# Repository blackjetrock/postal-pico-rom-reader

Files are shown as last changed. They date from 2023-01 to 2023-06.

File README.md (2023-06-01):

# Postal Pico ROM Reader

This is a ROM reader that is designed to be an easy to use, simple ROM dumping tool.
It should be possible to send the dumper to someone in the post, have them plug a ROM in and get
a dump of that ROM stored in the device flash. The device can then optionally dump
more ROMs and then be sent back to the person who wants the dumps. The dumps are then extracted from the 
device flash.

 <b>*** NOTE: Make sure pin 1 of the ROM is correctly aligned with pin 1 on the socket when inserting it ***</b>

The dumper can also dump ROM contents to the USB port it is powered by.



Hardware
========

The dumper is basically just a Pico attached to a ROM socket with serial resistors. It is making use of the 
possible/probably 5V tolerance of its GPIO lines-*-. The control signals are attached through low value 
resistors as they drive the ROM and aren't subject to 5V. The data lines are 5V and come into the Pico
though cowardly 28K resistors. 

Firmware
========

The firmware uses the USB serial port for interactions with the user. It uses the flash of the Pico for firmware 
and also has configuration data stored in part of the flash. ROM dumps stored in several 'slots' of 16K each so
an external non-volatile device isn't needed.
the USB serial has a menu system that can be entered at boot-up and used to set the non-volatile
configuration data that determines how the dumper will work. Slots can be cleared etc and data dumped from the menu
system.

The dumper can be set up to dump to USB or dump data to a flash slot using the configuration menu. When dumping to a 
slot the data is also dumped to USB. Once all slots are full the dumper will not over-write any slots with new dumps,
but the device can still be used as a dumper with a USB data dump.

To delete the slots a menu option is used, and several hoops have to be jumped through.

There are a couple of counters that count the number of USB dumps that the dumper has taken and the number of slot dumps it has performed.

-*-I saw a post on the internet, which if it really is by Eben Upton, says that the Pico GPIOs are
5V tolerant, but not 5V5 tolerant as inputs.

See here:

https://hackaday.com/2022/09/25/pi-pico-w-does-pcmcia-gets-this-ibm-pc110-online/#comment-6516402

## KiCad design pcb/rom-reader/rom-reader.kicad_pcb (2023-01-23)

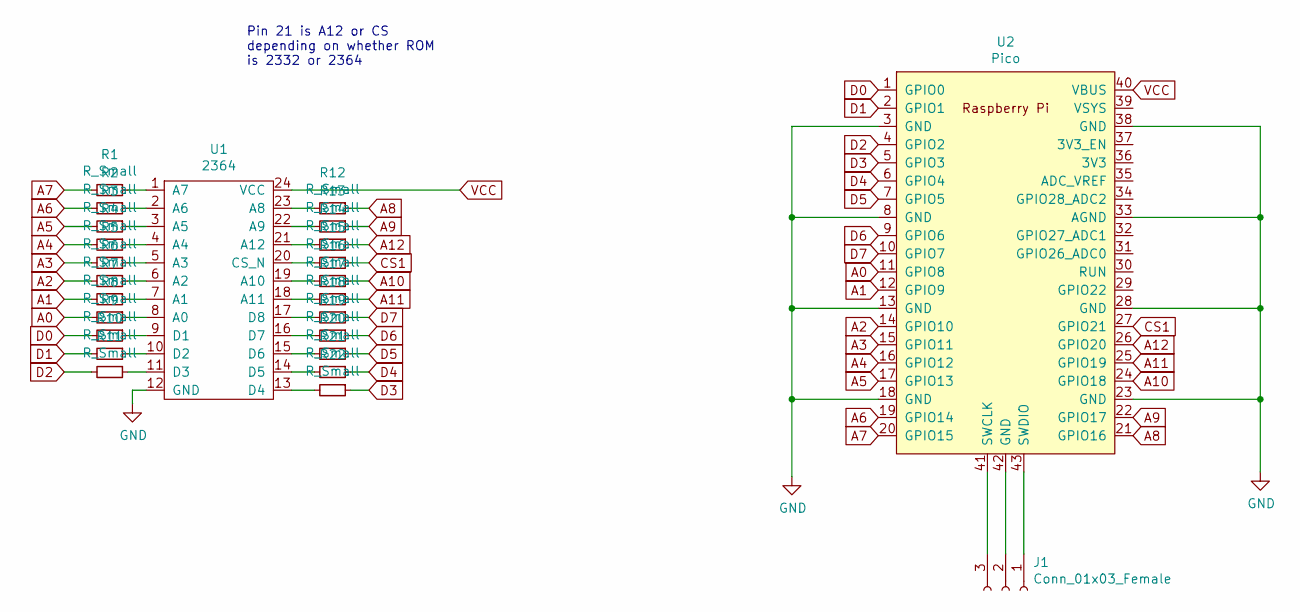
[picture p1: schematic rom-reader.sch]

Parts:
J1: Conn_01x03_Female; PinHeader_1x03_P2.54mm_Vertical
R1, R2, R3, R4, R5, R6, R7, R8, R9, R10, R11, R12, R13, R14, R15, R16, R17, R18, R19, R20, R21, R22: R_Small; R_0805_2012Metric_Pad1.20x1.40mm_HandSolder
U1: 2364; DIP-24_W15.24mm
U2: Pico; RPi_Pico_SMD_TH

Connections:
A0: R8.2, U2.11 (GPIO8)
A1: R7.2, U2.12 (GPIO9)
A2: R6.2, U2.14 (GPIO10)
A3: R5.2, U2.15 (GPIO11)
A4: R4.2, U2.16 (GPIO12)
A5: R3.2, U2.17 (GPIO13)
A6: R2.2, U2.19 (GPIO14)
A7: R1.2, U2.20 (GPIO15)
A8: R12.1, U2.21 (GPIO16)
A9: R13.1, U2.22 (GPIO17)
A10: R16.1, U2.24 (GPIO18)
A11: R17.1, U2.25 (GPIO19)
A12: R14.1, U2.26 (GPIO20)
CS1: R15.1, U2.27 (GPIO21)
D0: R9.2, U2.1 (GPIO0)
D1: R10.2, U2.2 (GPIO1)
D2: R11.2, U2.4 (GPIO2)
D3: R22.1, U2.5 (GPIO3)
D4: R21.1, U2.6 (GPIO4)
D5: R20.1, U2.7 (GPIO5)
D6: R19.1, U2.9 (GPIO6)
D7: R18.1, U2.10 (GPIO7)
GND: U1.12 (GND), U2.3 (GND), U2.8 (GND), U2.13 (GND), U2.18 (GND), U2.23 (GND), U2.28 (GND), U2.33 (AGND), U2.38 (GND)
unnamed: J1.1, U2.43 (SWDIO)
unnamed: J1.2, U2.42 (GND)
unnamed: J1.3, U2.41 (SWCLK)
unnamed: R1.1, U1.1 (A7)
unnamed: R2.1, U1.2 (A6)
unnamed: R3.1, U1.3 (A5)
unnamed: R4.1, U1.4 (A4)
unnamed: R5.1, U1.5 (A3)
unnamed: R6.1, U1.6 (A2)
unnamed: R7.1, U1.7 (A1)
unnamed: R8.1, U1.8 (A0)
unnamed: R9.1, U1.9 (D1)
unnamed: R10.1, U1.10 (D2)
unnamed: R11.1, U1.11 (D3)
unnamed: R12.2, U1.23 (A8)
unnamed: R13.2, U1.22 (A9)
unnamed: R14.2, U1.21 (A12)
unnamed: R15.2, U1.20 (CS_N)
unnamed: R16.2, U1.19 (A10)
unnamed: R17.2, U1.18 (A11)
unnamed: R18.2, U1.17 (D8)
unnamed: R19.2, U1.16 (D7)
unnamed: R20.2, U1.15 (D6)
unnamed: R21.2, U1.14 (D5)
unnamed: R22.2, U1.13 (D4)
VCC: U1.24 (VCC), U2.40 (VBUS)

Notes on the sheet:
Pin 21 is A12 or CS depending on whether ROM is 2332 or 2364

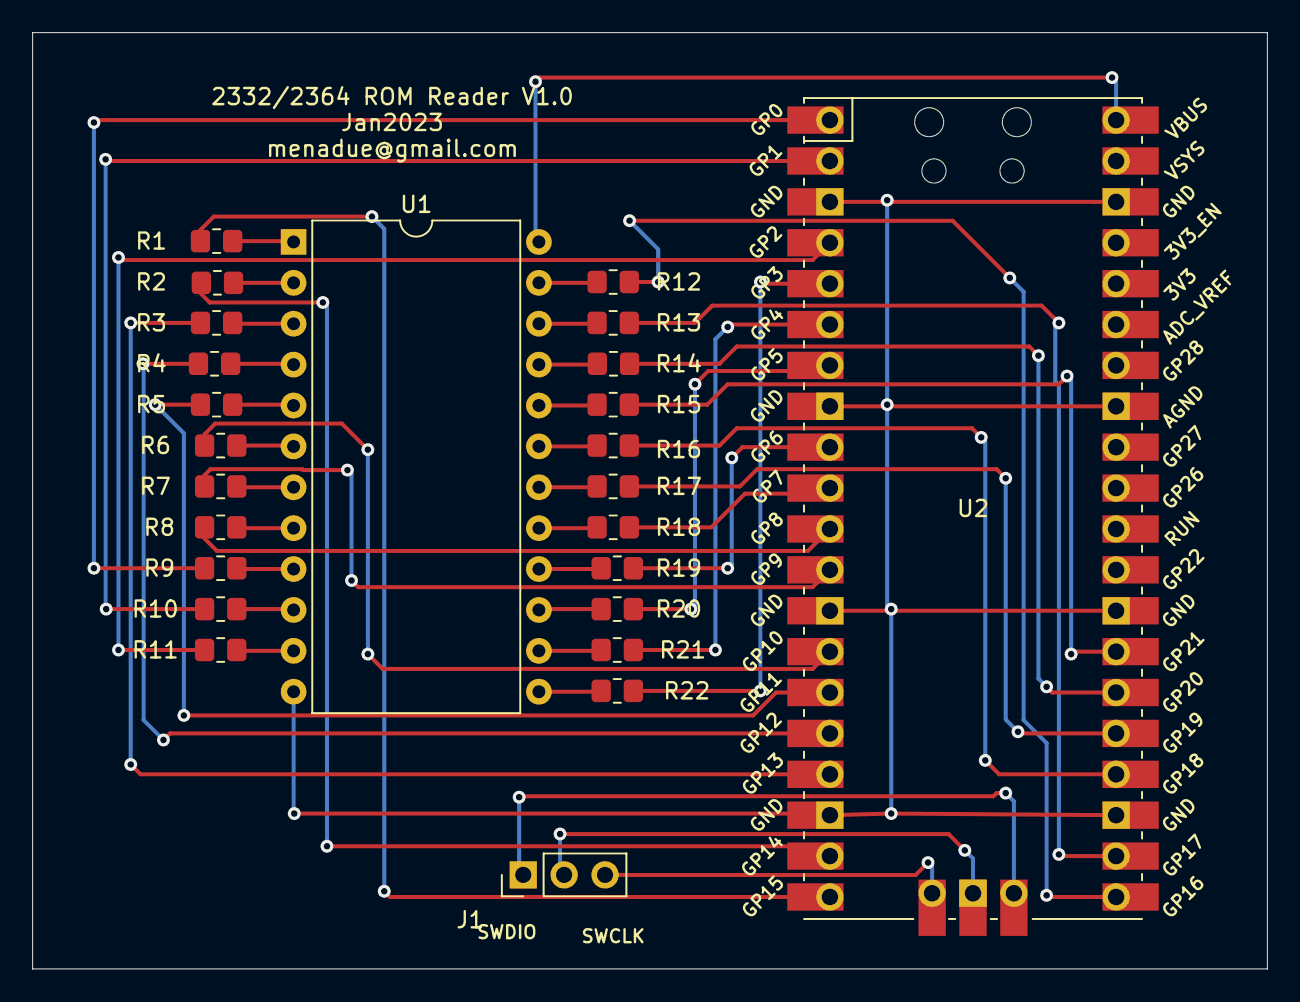
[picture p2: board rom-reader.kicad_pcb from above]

Board: 2 copper layers, 76.7 x 58.2 mm, 25 parts (0 on the bottom side), 49 nets.

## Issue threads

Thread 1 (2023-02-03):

Add license information

vazhnov, 2023-02-03:
Hello!

I found this project from https://hackaday.com/2023/02/02/a-disposable-dumper-for-rom-chips-with-a-pi-pico/

Could you please add information about the license of this repository — is it allowed to copy, change and use the code and design files in any purpose?
It would be great to see any popular open source license.

vazhnov, 2023-02-03:
Sounds like MIT for a code and CC0 / CC-BY for PCB files :)

vazhnov, 2023-02-03:
GPL is good for a code (if you know why some developers don't like GPL) but probably it is not clear for PCB files. I'm not **so** good in licensing.

Anyway it is much better than no license at all (100% proprietary).

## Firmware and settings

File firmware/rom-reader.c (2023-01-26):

////////////////////////////////////////////////////////////////////////////////
//
// Pico ROM Reader
//
// Reads data out of a 24 pin EPROM
// Data is dumped onto the USB serial
//
// A startup option allows configuration data to be set up.
// At the top of flash memory we have two areas. One holds config
// data and one holds slots for ROM dumps. The tool only works with up to
// 16K ROMs so we have 16K slots. Slots are only ever filled by the dump code
// once full the slot have to be deleted with a flash sector erase.
//
////////////////////////////////////////////////////////////////////////////////

#include <ctype.h>
#include <stdio.h>
#include <string.h>
#include <stdlib.h>
#include <time.h>
#include "pico/stdlib.h"
//##include "hardware/pio.h"
//##include "hardware/clocks.h"
#include "hardware/flash.h"

// Use this if breakpoints don't work
#define DEBUG_STOP {volatile int x = 1; while(x) {} }

////////////////////////////////////////////////////////////////////////////////
//
//

// Only scan once, if multiple dumps needed then use a loop around the entire tool
// This makes the post processing easier.

#define NUM_SCANS    1
#define SLOT_SIZE    (16*1024)

// How many slots there are. We could have very many slots, why not?
#define NUM_SLOTS    50

//-----------------------------------------------------------------------------

// Config sector
#define FLASH_CONFIG_OFFSET (1024 * 1024)
uint8_t *flash_config_contents = (uint8_t *) (XIP_BASE + FLASH_CONFIG_OFFSET);

// ROM image slots
#define FLASH_SLOT_OFFSET (1028 * 1024)
uint8_t *flash_slot_contents   = (uint8_t *) (XIP_BASE + FLASH_SLOT_OFFSET);


//--------------------------------------------------------------------------------

typedef enum
  {
   USB_DUMP = 0,
   SLOT_DUMP,
   NUM_SETUP_MODES,
  } SETUP_MODE;

char *setup_mode_name[NUM_SETUP_MODES] =
  {
   "USB DUMP",
   "SLOT_DUMP",
  };

typedef struct {
  int valid_a;     // magic number and an 
  int valid_b;     // inverterted magic number
  int mode;        // Mode we are in
  int usb_dump_count;   // Incremented after every dump
  int slot_dump_count;  // Incremented after every slot dump
} CONFIG_RECORD;

CONFIG_RECORD *config_record = (CONFIG_RECORD *) (XIP_BASE + FLASH_CONFIG_OFFSET);
CONFIG_RECORD copy_config_record;

#define CONFIG_MAGIC_A 0xCFAA0134
#define CONFIG_MAGIC_B 0xCFBB5623

// RAM slot which we copy to flash once filled
uint8_t slot_data[SLOT_SIZE];

//--------------------------------------------------------------------------------

void dump_slot(int slotnum);
void display_slot_map(void);
void clear_slot_data(void);

//------------------------------------------------------------------------------

const int LED_PIN = 25;

const int D0_PIN = 0;
const int D1_PIN = 1;
const int D2_PIN = 2;
const int D3_PIN = 3;
const int D4_PIN = 4;
const int D5_PIN = 5;
const int D6_PIN = 6;
const int D7_PIN = 7;

//
// The address lines (always inputs)
//
const int  A0_PIN  =  8;
const int  A1_PIN  =  9;
const int  A2_PIN  = 10;
const int  A3_PIN  = 11;
const int  A4_PIN  = 12;
const int  A5_PIN  = 13;
const int  A6_PIN  = 14;
const int  A7_PIN  = 15;
const int  A8_PIN  = 16;
const int  A9_PIN  = 17;
const int  A10_PIN = 18;
const int  A11_PIN = 19;
const int  A12_PIN = 20;
const int  A13_PIN = 21;  // Actually CS pin sometimes but can scan as if it was an address line

// Arrays for setting GPIOs up
#define NUM_ADDR 14
#define NUM_DATA 8

const int address_pins[NUM_ADDR] =
  {
   A0_PIN,
   A1_PIN,
   A2_PIN,
   A3_PIN,
   A4_PIN,
   A5_PIN,
   A6_PIN,
   A7_PIN,
   A8_PIN,
   A9_PIN,
   A10_PIN,
   A11_PIN,
   A12_PIN,
   A13_PIN,   // Could be CS pin
  };

const int data_pins[NUM_DATA] =
  {
   D0_PIN,
   D1_PIN,
   D2_PIN,
   D3_PIN,
   D4_PIN,
   D5_PIN,
   D6_PIN,
   D7_PIN,
  };

////////////////////////////////////////////////////////////////////////////////
//
// Set the address lines to a value
//
////////////////////////////////////////////////////////////////////////////////

void set_address(int addr)
{
  for(int i=0; i<NUM_ADDR; i++)
    {
      if( addr & (1<<i) )
	{
	  gpio_put(address_pins[i], 1);
	}
      else
	{
	  gpio_put(address_pins[i], 0);
	}
    }
}


int read_data(void)
{
  int result = 0;
  
  for(int i=0; i<NUM_DATA; i++)
    {
      if( gpio_get(data_pins[i]) )
	{
	  result |= (1 << i);
	}
    }
  return(result);
}

////////////////////////////////////////////////////////////////////////////////


void print_hex(uint8_t *buf, int len)
{
  for (size_t i = 0; i < len; ++i)
    {
      if((i % 16) == 0)
	{
	  printf("\n");
	}
      
      printf("%02x ", buf[i]);
    }
}

////////////////////////////////////////////////////////////////////////////////

void prompt(void)
{
  printf("\n>");
}

void setup_menu(void)
{
  printf("\nSetup");
  printf("\n=====");
  printf("\n");
  printf("\n?: Display menu");
  printf("\nq: Quit");
  printf("\nc: Clear config settings");
  printf("\nC: Clear slot data");
  printf("\nd: Display config settings");
  printf("\np: Print information");
  printf("\nP: Dump config sector");
  printf("\nU: Set USB dump mode");
  printf("\nS: Set slot dump mode");
  printf("\nM: Display slot map");
  printf("\nr: Display slot");
  printf("\nz: Zero USB dump count");
  printf("\nZ: Zero Slot dump count");
}

void erase_config_sector(void)
{
  flash_range_erase(FLASH_CONFIG_OFFSET, FLASH_SECTOR_SIZE);
}

void erase_slot_data(void)
{
  flash_range_erase(FLASH_SLOT_OFFSET, SLOT_SIZE*NUM_SLOTS);
}

void program_config_record(CONFIG_RECORD *data)
{
  flash_range_program(FLASH_CONFIG_OFFSET,(uint8_t *) data, sizeof(CONFIG_RECORD));
}

void write_config_record(CONFIG_RECORD *cfg_rec)
{
  // Make record valid
  cfg_rec->valid_a = CONFIG_MAGIC_A;
  cfg_rec->valid_b = CONFIG_MAGIC_B;
  
  erase_config_sector();
  program_config_record(cfg_rec);
}

void zero_usb_dump_count(void)
{
  copy_config_record = *config_record;
  copy_config_record.usb_dump_count = 0;
  write_config_record(&copy_config_record);
}

void zero_slot_dump_count(void)
{
  copy_config_record = *config_record;
  copy_config_record.slot_dump_count = 0;
  write_config_record(&copy_config_record);
}

void increment_usb_dump_count(void)
{
  copy_config_record = *config_record;
  (copy_config_record.usb_dump_count)++;
  write_config_record(&copy_config_record);
}

void increment_slot_dump_count(void)
{
  copy_config_record = *config_record;
  (copy_config_record.slot_dump_count)++;
  write_config_record(&copy_config_record);
}

//--------------------------------------------------------------------------------

void write_data_to_slot(uint8_t *data, int slotnum)
{
  printf("\nWriting data to slot %d", slotnum);

  flash_range_program(FLASH_SLOT_OFFSET + (SLOT_SIZE * slotnum), (uint8_t *) data, SLOT_SIZE);

  printf("\nData written");
  
}

//--------------------------------------------------------------------------------
//

int slot_is_blank(int slotnum)
{
  int blank = 0;
  
  // See if all bytes in this slot are 0xff
  // Assume blank

  blank = 1;

  for(int j=0; j<SLOT_SIZE;j++)
    {
      if( *(flash_slot_contents+slotnum*SLOT_SIZE+j) !=0xFF )
	{
	  // Not blank
	  blank = 0;
	  break;
	}
    }
  
  if( blank )
    {
      // We found a slot, return its index
      return(1);
    }

  return(0);
}

//--------------------------------------------------------------------------------
//
// Find a slot that has no data in it, i.e. is full of 0xFF
// returns either the slot number or -1 if none are blank

int find_blank_slot(void)
{
  int slotnum = -1;
  
  for(slotnum=0; slotnum<NUM_SLOTS; slotnum++)
    {
      if( slot_is_blank(slotnum) )
	{
	  return(slotnum);
	}
    }

  return(-1);
}

char *get_mode_name(int mode)
{
  switch(mode)
    {
    case USB_DUMP:
    case SLOT_DUMP:
      return(setup_mode_name[mode]);      
      break;

    default:
      return("Unknown");
      break;
    }
}

////////////////////////////////////////////////////////////////////////////////
//
// Check for entry into the setup code
//
////////////////////////////////////////////////////////////////////////////////

void check_config_entry(void)
{
  int c;
  int key_pressed = 0;

  printf("\nPress any key to enter setup...\n");
  
  // Wait for a while and see if a keypress occurred
  for(int i=0; i<5; i++)
    {
      printf("  %d...", i);
      
      sleep_ms(1000);

      if( (c = getchar_timeout_us(1000)) != PICO_ERROR_TIMEOUT )
	{
	  if( (c != 0) && (c != 255) )
	    {
	      key_pressed = 1;
	      break;
	    }
	}
    }

  if( key_pressed )
    {
      printf("\nkey %d pressed", c);

      // Key was pressed, enter setup loop

      int done = 0;

      setup_menu();
      prompt();
      
      while(!done)
	{
	  if( (c = getchar_timeout_us(1000)) != PICO_ERROR_TIMEOUT )
	    {
	      // handle command
	      switch(c)
		{
		case '?':
		  setup_menu();
		  break;
		  
		case 'q':
		  done = 1;
		  break;

		case 'd':
		  printf("\nConfiguration data:");
		  printf("\n");
		  break;
		  
		case 'c':
		  // Erase config sector
		  erase_config_sector();

		  break;

		case 'C':
		  clear_slot_data();
		  break;
		  
		case 'U':
		  // Set USB mode
		  // Read config into RAM
		  copy_config_record = *config_record;
		  copy_config_record.mode = USB_DUMP;
		  write_config_record(&copy_config_record);
		  break;

		case 'S':
		  // Set SLOT mode
		  // Read config into RAM
		  copy_config_record = *config_record;
		  copy_config_record.mode = SLOT_DUMP;
		  write_config_record(&copy_config_record);
		  break;
		  
		case 'r':
		  {
		    int slot_number;
		    
		    printf("\nSlot number:");
		    scanf("%d", &slot_number);
		    dump_slot(slot_number);
		  }
		  break;

		case 'M':
		  display_slot_map();
		  break;

		case 'z':
		  zero_usb_dump_count();
		  break;

		case 'Z':
		  zero_slot_dump_count();
		  break;
		  
		case 'P':
		  // Print flash config data sector
		  print_hex(flash_config_contents, FLASH_SECTOR_SIZE);
		  break;
		  
		case 'p':
		  // print information
		  printf("\nFlash sector size: %d", FLASH_SECTOR_SIZE);
		  printf("\nFlash page size  : %d", FLASH_PAGE_SIZE);

		  printf("\nConfiguration data");
		  printf("\n");
		  print_hex(flash_config_contents, sizeof(CONFIG_RECORD));
		  printf("\n");

		  if( (config_record->valid_a == CONFIG_MAGIC_A) && (config_record->valid_b == CONFIG_MAGIC_B ))
		    {
		      printf("\nConfiguration valid");
		      printf("\nMode           : %s", get_mode_name(config_record->mode));
		      printf("\nUSB dump count : %d", config_record->usb_dump_count);
		      printf("\nSlot dump count: %d", config_record->slot_dump_count);
		      printf("\n");
		    }
		  else
		    {
		      printf("\nConfiguration NOT valid");
		    }
		  break;
		  
		default:
		  printf("\nKey press unknown: %d", c);
		  break;
		}
	      
	      prompt();
	    }
	}
    }
}


////////////////////////////////////////////////////////////////////////////////
//
// USB Dump mode
//
////////////////////////////////////////////////////////////////////////////////

void usb_dump(void)
{
  // We scan the device twice, so we can compare the two scans and check that data is
  // consistent on each scan. Data is dumped to the slot in RAM so we can use this code
  // for the slot dump mode and just copy data to flash afterwards if needed.

  int scan    = 0;
  int addr    = 0;
  int byte    = 0;
  int ascii_i = 0;
  int sloti   = 0;
  
#define LINELEN 64
  
  char ascii[LINELEN+1] = "";
  
  for(addr=0; addr < (1<<NUM_ADDR); addr++)
    {
      ascii_i = addr % LINELEN;
      
      if( (addr % LINELEN) == 0 )
	{
	  printf("\n%04X: ", addr);
	}
      
      set_address(addr);
      sleep_ms(1);
      byte = read_data();

      slot_data[sloti++] = byte;

      if( sloti > SLOT_SIZE )
	{
	  printf("\nSlot size inconsistent");
	}
      
      if( isprint(byte))
	{
	  ascii[ascii_i] = byte & 0xFF;
	}
      else
	{
	  ascii[ascii_i] = '.';    
	}
      
      printf("%02X ", byte);
      
      if( ascii_i == (LINELEN-1) )
	{
	  ascii[LINELEN] = '\0';
	  printf("  %s", ascii);
	}
    }

  // Sucessful dump, increment the count
  increment_usb_dump_count();
}

////////////////////////////////////////////////////////////////////////////////
//
// Slot Dump mode
//
////////////////////////////////////////////////////////////////////////////////

// We dump the ROM to a RAM slot then copy the data into a blank slot. If no blank
// slots then we don't copy any data.
// The ROM is dumped to RAM and displayed on USB as well, so if the slots are full
// then a USB dump still occurs

void slot_dump(void)
{
  int slotnum = -1;
  
  // Do a USB dump, which will save the data for us in slot_data[] and also
  // has done a 'backup' USB dump for us.

  // this will increment the USB dump counter
  usb_dump();

  // We have the data in RAM, now try to find somewhere in flash to store it
  slotnum = find_blank_slot();

  if( slotnum == -1 )
    {
      printf("\nNo free slots available");

      // No slots, we can do no more
      // Slot dump counter not incremented
      return;
    }

  // We have a slot to store the data in, so write it
  write_data_to_slot(slot_data, slotnum);
  increment_slot_dump_count();
}

void display_slot_map(void)
{
  printf("\nSlot Map\n");
  printf("\n\nSlot size:%d bytes\n", SLOT_SIZE);
  
  for(int s=0; s<NUM_SLOTS; s++)
    {
      printf("\n%02d: %s", s, slot_is_blank(s)?"Blank":"Used ");
    }
  
  printf("\n");
}

void dump_slot(int slotnum)
{
  printf("\nSlot %d\n", slotnum);
  
  print_hex(flash_slot_contents+slotnum*SLOT_SIZE, SLOT_SIZE);

  printf("\n");
}

void clear_slot_data(void)
{
  char answer[100];
  
  printf("\n*** CLEAR SLOT DATA ***\n");
  printf("\n\nAre you sure? (Yes/No):");

  scanf("%s", answer);
  srand(time_us_32());
  
  if( strcmp(answer, "Yes") == 0 )
    {
      int code = rand();
      int code_answer = code+1;
      
      printf("\n\nEnter code:%d:", code);

      scanf("%d", &code_answer);
      
      if( code==code_answer )
	{
	  printf("\nDeleting slot data in 10 seconds...");
	  for(int ct=1; ct<=10; ct++)
	    {
	      sleep_ms(1000);
	      printf("\n%d...", ct);
	    }
	  printf("\nDeleting...");
	  erase_slot_data();
	  printf("\nDone");
	}
    }
}

////////////////////////////////////////////////////////////////////////////////
//
//
//
////////////////////////////////////////////////////////////////////////////////

int main()
{

  char line[80];

  stdio_init_all();

  sleep_ms(3000);
  
  printf("\nPico ROM Reader V1.0\n");
  sleep_ms(1000);

  check_config_entry();
  
#if TEST_STDIO
  {
  int count;
  while (true)
    {
      count++;
      
      if( (count % 1000000) == 0 )
	{
	  sprintf(line, "\nRP2040: %d", count);
	  printf(line);
	}
    }
  }
#endif

  // LED ON solid
  gpio_init(LED_PIN);
  gpio_set_dir(LED_PIN, GPIO_OUT);
  gpio_put(LED_PIN, 1);
  
  printf("\nSetting GPIOs...");
  sleep_ms(1000);
  
  // Address lines are driven
  for (int i=0; i<NUM_ADDR; i++)
    {
      // Set up directions for the control lines
      gpio_init(address_pins[i]);
      gpio_set_dir(address_pins[i], GPIO_OUT);
    }

  // Data lines are inputs
  for (int i=0; i<NUM_DATA; i++)
    {
      // Set up directions for the control lines
      gpio_init(data_pins[i]);
      gpio_set_dir(data_pins[i], GPIO_IN);
    }


  // Perform the mode that was requested
  switch(config_record->mode)
    {
    case USB_DUMP:
      printf("\nUSB Dump\n");
      sleep_ms(1000);
      usb_dump();
      break;

    case SLOT_DUMP:
      printf("\nSlot Dump\n");
      sleep_ms(1000);
      slot_dump();
      break;

    default:
      printf("\nUnknown mode.");
      break;
    }

  // All done, flash the LED
  printf("\nDone.");
  printf("\n");
  
  while(1)
    {
      sleep_ms(250);
      gpio_put(LED_PIN, 0);
      sleep_ms(250);
      gpio_put(LED_PIN, 1);
    }
}
